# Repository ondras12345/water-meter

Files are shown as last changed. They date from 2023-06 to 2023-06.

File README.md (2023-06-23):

# Water meter
This is a simple sensor for Sensus PN16 water meters.
It uses an infrared LED and phototransistor to sense the metal disk on the
x0.0001 m³ pointer wheel.

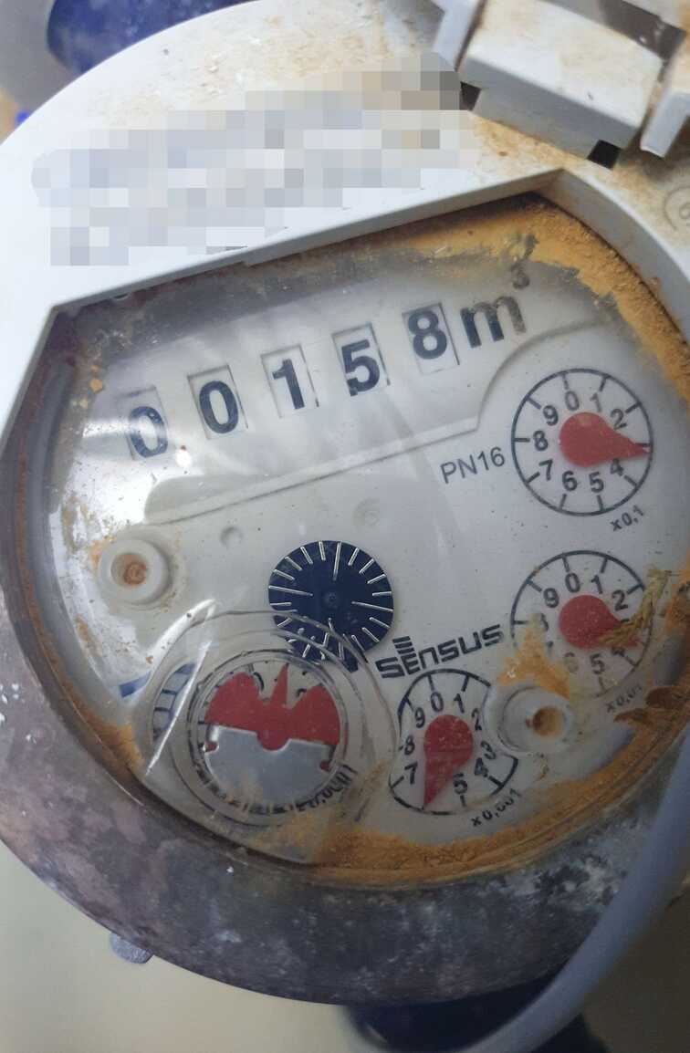
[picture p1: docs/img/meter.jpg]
Sensus PN16 water meter


Sensus do sell an inductive sensor for this type of meter (Sensus HRI),
but it is a bit pricey and needs batteries to operate.

I own a small CNC mill, so I decided to mill a custom PCB that matches the
shape of the meter. This allows me to easily mount it to the meter without the
need for custom 3D printed parts.

## Hardware
KiCAD designs for the PCB are available in the [`hardware`](hardware/)
directory.

**WARNING**: Make sure to read the notes in the schematic. Since this was a
one-off project, I did not spend much time fixing potential problems I
discovered after milling the board.

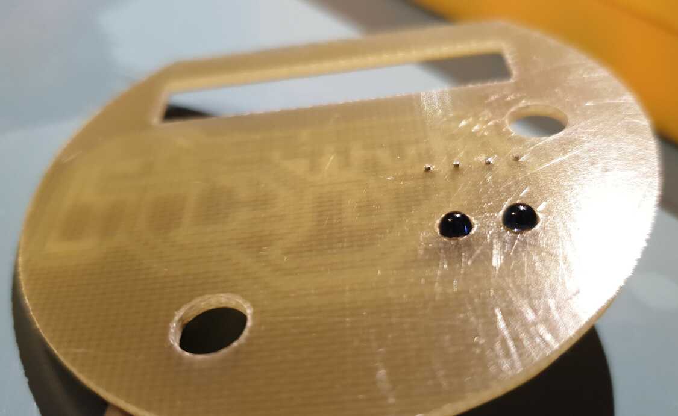
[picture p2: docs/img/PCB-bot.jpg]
Bottom side of the PCB with IR LED and phototransistor protruding from the top side

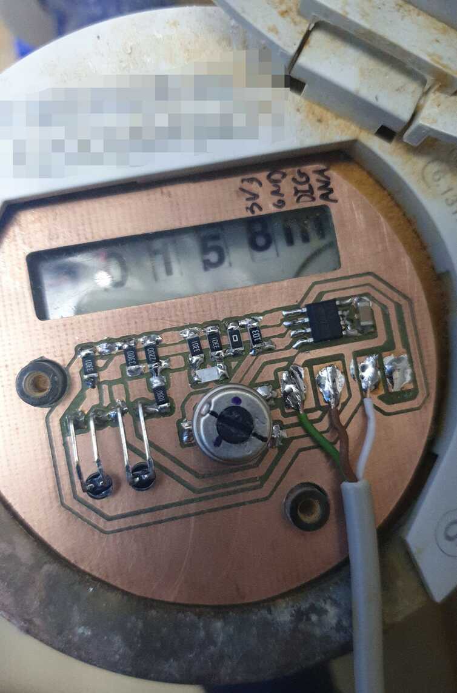
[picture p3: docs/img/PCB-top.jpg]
PCBA mounted on the water meter


## Software
This part is a bit complicated. I connected the sensor to an STM32F103 board
that handles many other sensors in the room. I don't want to share the whole
source code (it wouldn't make much sense for anyone other than me), but I will
try to include the relevant parts here:

```cpp
#define DEBOUNCE_FREQUENCY 50  // HZ
// ...

unsigned int water_meter_pulses = 0;
static volatile unsigned int pulses = 0;

#define SAMPLING_FREQUENCY DEBOUNCE_FREQUENCY  // Hz
// max flow rate should be 1,39 l / s (2*Qn)
// 2 pulses per revolution
#define DEBOUNCE_TIME 320  // ms
#define INTEGRATOR_MAX (DEBOUNCE_TIME * SAMPLING_FREQUENCY / 1000)
/**
 * Read water meter state.
 * This function should be called from a timer ISR
 * DEBOUNCE_FREQUENCY times per second.
 */
void water_meter_debounce()
{
    static unsigned int integrator = 0;

    if (digitalRead(pin_water_meter))
    {
        if (integrator < INTEGRATOR_MAX) integrator++;
    }
    else
    {
        if (integrator > 0) integrator--;
    }

    static bool output = false;
    static bool prev_output = false;
    static bool first = true;
    if (integrator == 0)
    {
        output = false;
        if (first)
        {
            first = false;
            prev_output = output;
        }
    }

    if (integrator >= INTEGRATOR_MAX)
    {
        output = true;
        if (first)
        {
            first = false;
            prev_output = output;
        }
        // this should never be needed
        integrator = INTEGRATOR_MAX;
    }

    if (output != prev_output)
    {
        prev_output = output;
        pulses++;  // incremented at every edge (0.5 l)
    }
}

void water_meter_setup()
{
    // extra pull-up might help with noise immunity
    pinMode(pin_water_meter, INPUT_PULLUP);
}

void water_meter_loop()
{
    noInterrupts();
    water_meter_pulses = pulses;
    interrupts();
}

// mqtt.cpp
void mqtt_loop()
{
    // ...
    static unsigned int prev_water_meter_pulses = 0;
    if (force_report || water_meter_pulses != prev_water_meter_pulses)
    {
        prev_water_meter_pulses = water_meter_pulses;
        char buff[3*sizeof(water_meter_pulses) + 1]; // >= number of digits + null
        snprintf(buff, sizeof buff, "%u", water_meter_pulses);
        MQTTClient.publish(MQTTtopic_water_meter_pulses, buff, true);
    }
}
```

## Home Assistant
[Home Assistant](https://www.home-assistant.io/) can be used to receive MQTT
messages sent by the device and track water consumption.

```yaml
recorder:
  exclude:
    entities:
      # do not store the intermediate sensor's state history in the database
      - sensor.water_meter_pulses

mqtt:
  sensor:
    - name: Water meter pulses
      state_topic: rolety/tele/water_meter/pulses
      availability_topic: rolety/tele/availability
      unit_of_measurement: "pulses"

template:
  - sensor:
    - name: Water meter
      unit_of_measurement: "m³"
      state: '{{ states("sensor.water_meter_pulses") | int(0) / 2000.0 }}'
      availability: '{{ has_value("sensor.water_meter_pulses") }}'
      device_class: water
      state_class: total_increasing
```
`sensor.water_meter` has the proper `state_class` and `device_class`, so it
can be used with the [energy dashboard](https://www.home-assistant.io/dashboards/energy/).

## Similar projects
- http://jheyman.github.io/blog/pages/WirelessWaterMeter/

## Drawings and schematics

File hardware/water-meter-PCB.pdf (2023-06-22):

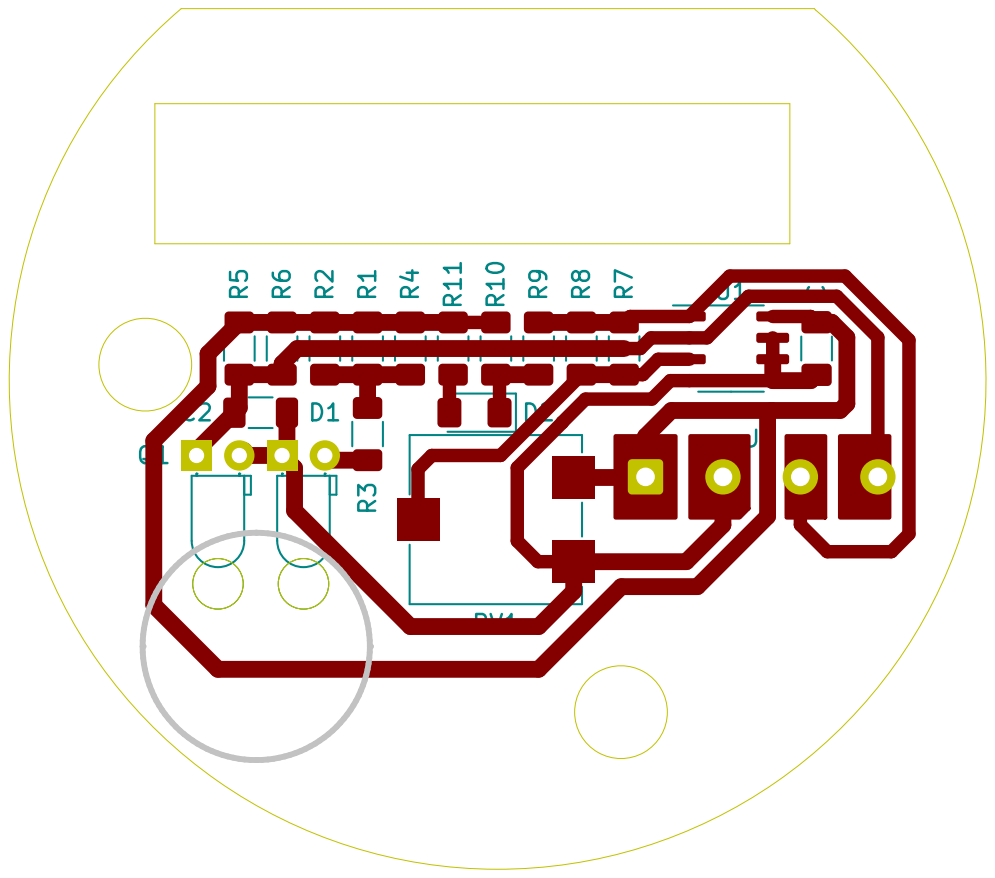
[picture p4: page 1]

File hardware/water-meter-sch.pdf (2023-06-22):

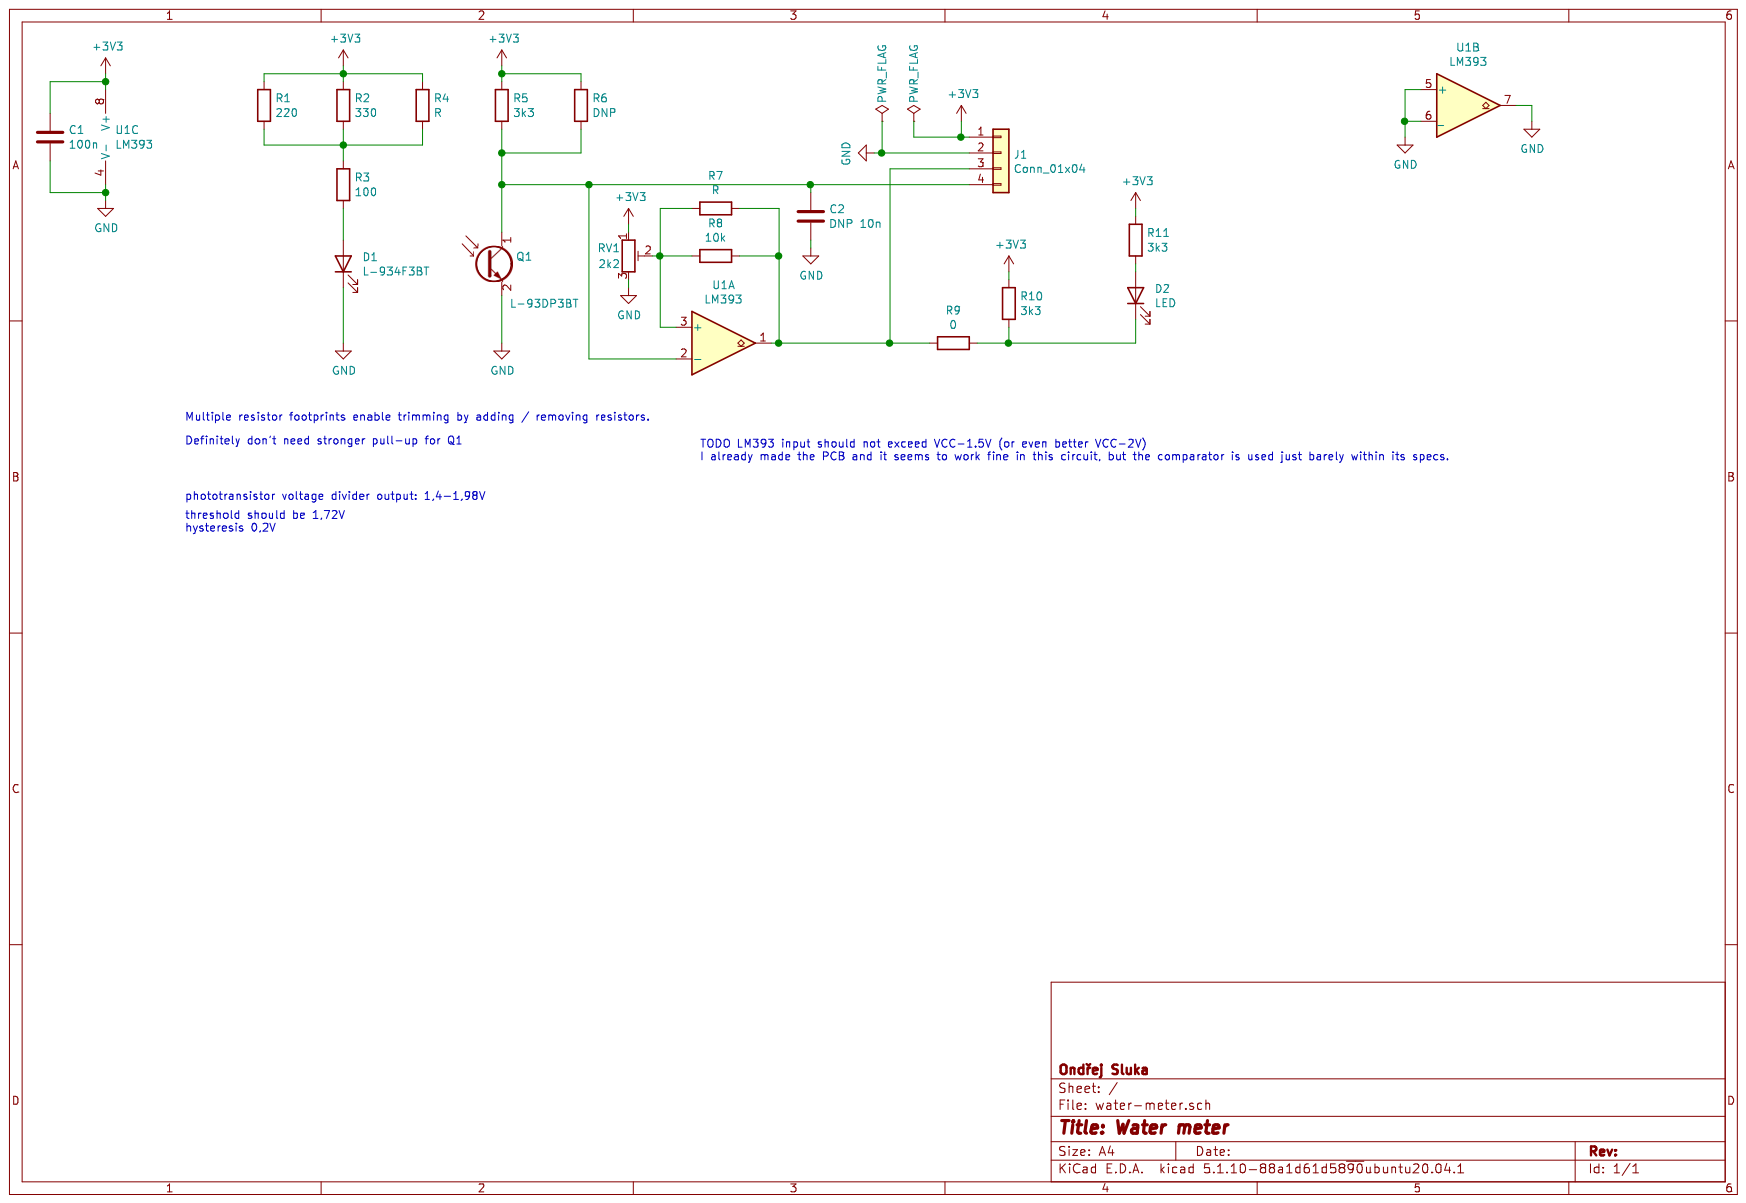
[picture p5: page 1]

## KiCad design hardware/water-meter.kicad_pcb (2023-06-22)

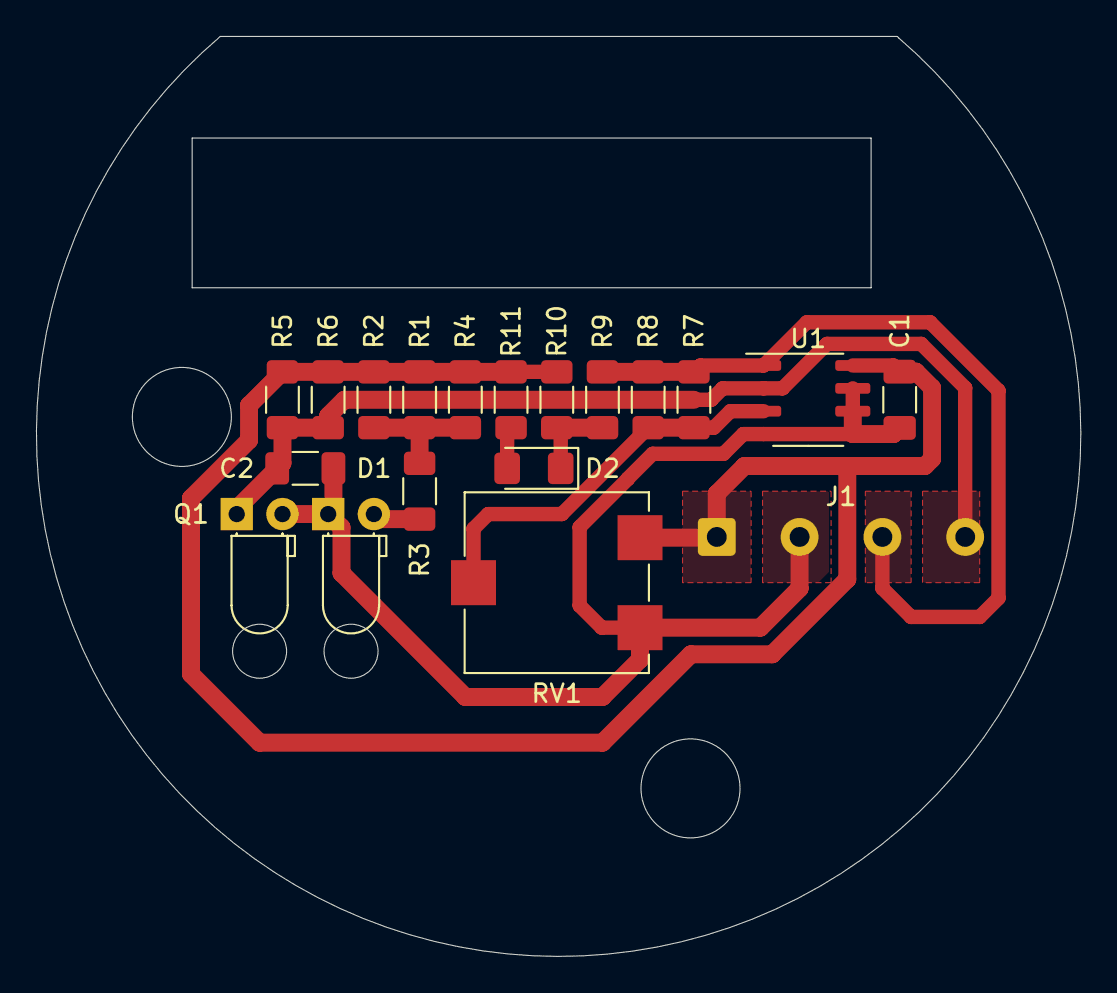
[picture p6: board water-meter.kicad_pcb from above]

Board: 2 copper layers, 58.0 x 51.1 mm, 19 parts (0 on the bottom side), 9 nets.

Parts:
C1: 100n; C_1206_3216Metric_Pad1.33x1.80mm_HandSolder
C2: 10n; C_1206_3216Metric_Pad1.33x1.80mm_HandSolder
D1: L-934F3BT; LED_D3.0mm_Horizontal_O1.27mm_Z2.0mm
D2: LED; LED_1206_3216Metric_Pad1.42x1.75mm_HandSolder
J1: Conn_01x04; SolderWire-0.5sqmm_1x04_P4.6mm_D0.9mm_OD2.1mm
Q1: L-93DP3BT; LED_D3.0mm_Horizontal_O1.27mm_Z2.0mm
R1, R4, R7: R; R_1206_3216Metric_Pad1.30x1.75mm_HandSolder
R2, R3: 100; R_1206_3216Metric_Pad1.30x1.75mm_HandSolder
R5, R6, R10, R11: 3k3; R_1206_3216Metric_Pad1.30x1.75mm_HandSolder
R8: 22k; R_1206_3216Metric_Pad1.30x1.75mm_HandSolder
R9: 0; R_1206_3216Metric_Pad1.30x1.75mm_HandSolder
RV1: 2k2; Potentiometer_ACP_CA9-VSMD_Vertical
U1: LM393; SOIC-8_3.9x4.9mm_P1.27mm

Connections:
+3V3: C1.1, J1.1, R1.1, R2.1, R4.1, R5.1, R6.1, R10.1, R11.1, RV1.1, U1.8
GND: C1.2, C2.2, D1.1, J1.2, Q1.2, RV1.3, U1.4, U1.5, U1.6, U1.7
unnamed: C2.1, J1.4, Q1.1, R5.2, R6.2, U1.2
unnamed: D1.2, R3.2
unnamed: D2.1, R9.1, R10.2
unnamed: D2.2, R11.2
unnamed: J1.3, R7.1, R8.1, R9.2, U1.1
unnamed: R1.2, R2.2, R3.1, R4.2
unnamed: R7.2, R8.2, RV1.2, U1.3

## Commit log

2023-06-22 Add project files
    [water-meter.kicad_pcb, water-meter.sch]
2023-06-22 Fix hardware design flaws
    ... hopefully. I didn't mill a new board. Instead, I just drilled larger
    holes and sanded the edge a bit.
    [water-meter.kicad_pcb]
